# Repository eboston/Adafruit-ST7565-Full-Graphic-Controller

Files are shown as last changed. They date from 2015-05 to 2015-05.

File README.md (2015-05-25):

# Adafruit-ST7565-Full-Graphic-Controller
3D Printer Controller based around the Adafruit ST7565 display

This is a simple project I started to utilize a couple displays I had gotten from 
Adafruit (http://www.adafruit.com/products/250).  Initially this is just for the
RAMPS 1.4 board utilizing the basic smart adapter running Marlin.  Plans are to expand 
the supported platforms to include the Smoothieboard with GLCD shield and the Printrboard 
Rev F4.

Initial support has been added to the devlopment branch of Marlin.

The PCB is Rev B and has not been built or tested yet.  It contains fixes for problems found in the Rev A board.

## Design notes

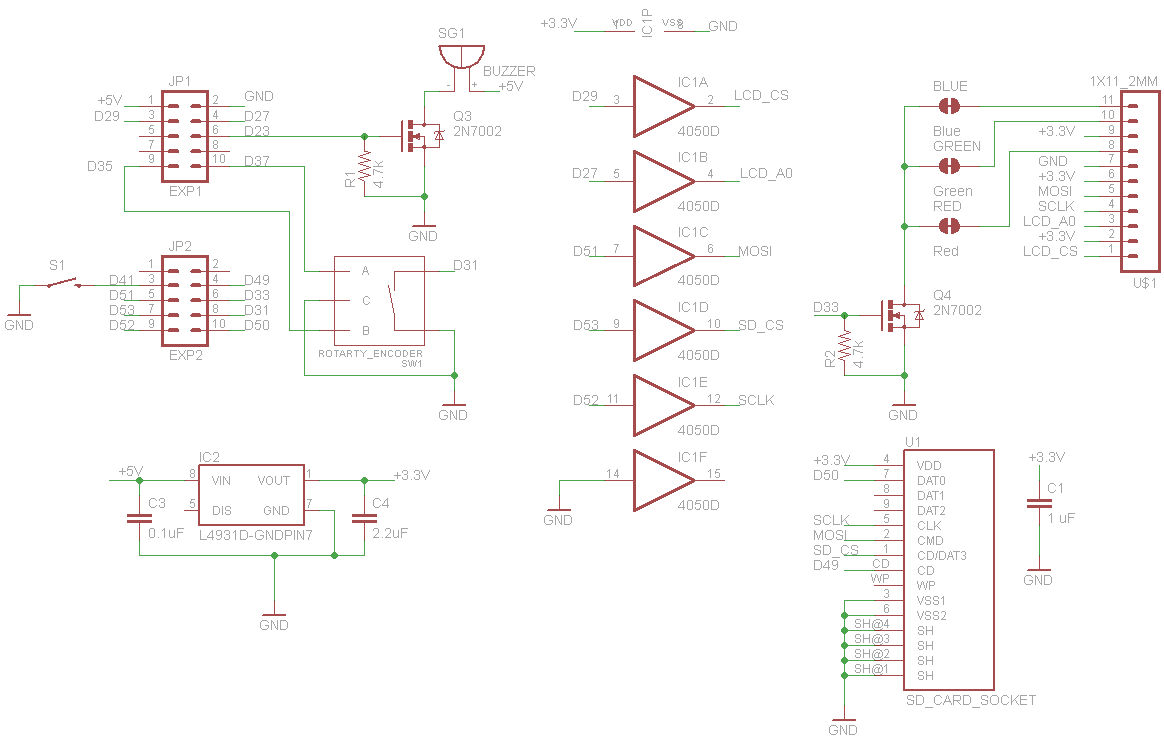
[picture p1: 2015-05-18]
Adafruit ST7565.png

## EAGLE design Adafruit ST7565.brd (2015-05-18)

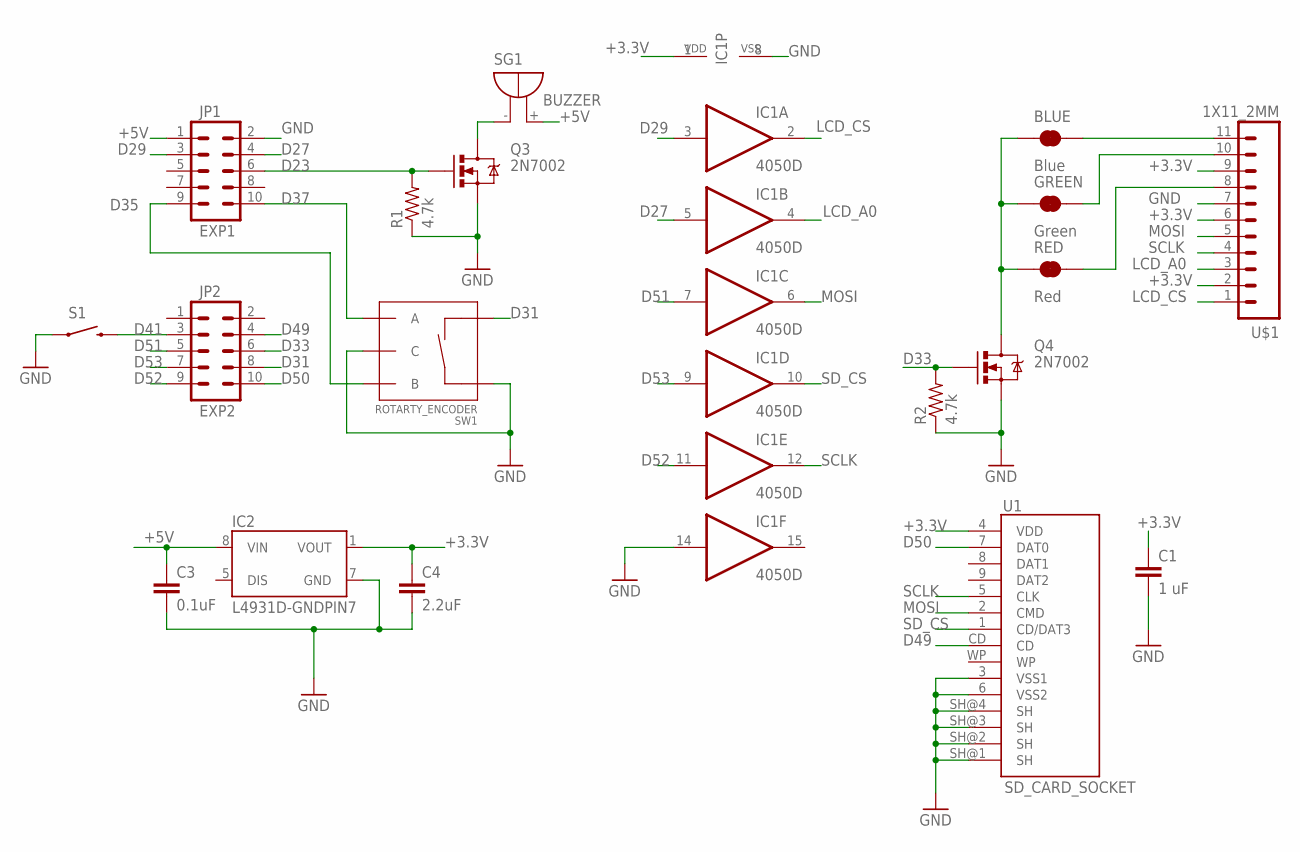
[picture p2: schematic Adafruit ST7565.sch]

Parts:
BLUE: Blue; PAD-JUMPER-2-NC_BY_TRACE_YES_SILK
C1: 1 uF; 1206
C3: 0.1uF; 1206
C4: 2.2uF; 1206
GREEN: Green; PAD-JUMPER-2-NC_BY_TRACE_YES_SILK
IC1: 4050D; SO16
IC2: L4931D-GNDPIN7; SO08
JP1: EXP1; 2X5-SHROUDED
JP2: EXP2; 2X5-SHROUDED
Q3, Q4: 2N7002; SOT23-3
R1, R2: 4.7k; 1206
RED: Red; PAD-JUMPER-2-NC_BY_TRACE_YES_SILK
S1: SWITCH-MOMENTARY-2PTH; TACTILE-PTH
SG1: BUZZER; F/QMBIII
SW1: ROTARTY_ENCODER; ROTARY_ENC_PLAIN
U1: SD_CARD_SOCKET; SD_1:1
U$1: 1X11_2MM

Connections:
+3.3V: C1.1, C4.1, IC1.1 (VDD), IC2.1 (VOUT), U1.4 (VDD), U$1.2, U$1.6, U$1.9
+5V: C3.1, IC2.8 (VIN), JP1.1, SG1.+ (-)
D23: JP1.6, Q3.1 (G), R1.2
D27: IC1.5 (I), JP1.4
D29: IC1.3 (I), JP1.3
D31: JP2.8, SW1.SW-
D33: JP2.6, Q4.1 (G), R2.2
D35: JP1.9, SW1.B
D37: JP1.10, SW1.A
D41: JP2.3, S1.3 (2)
D49: JP2.4, U1.CD
D50: JP2.10, U1.7 (DAT0)
D51: IC1.7 (I), JP2.5
D52: IC1.11 (I), JP2.9
D53: IC1.9 (I), JP2.7
GND: C1.2, C3.2, C4.2, IC1.8 (VSS), IC1.14 (I), IC2.7 (GND), JP1.2, Q3.2 (S), Q4.2 (S), R1.1, R2.1, S1.1, SW1.C, SW1.SW+, U1.3 (VSS1), U1.6 (VSS2), U1.SH@1 (SH), U1.SH@2 (SH), U1.SH@3 (SH), U1.SH@4 (SH), U$1.7
LCD_A0: IC1.4 (O), U$1.3
LCD_CS: IC1.2 (O), U$1.1
MOSI: IC1.6 (O), U1.2 (CMD), U$1.5
unnamed: Q3.3 (D), SG1.- (+)
unnamed: BLUE.1, GREEN.1, Q4.3 (D), RED.1
unnamed: RED.2, U$1.8
unnamed: GREEN.2, U$1.10
unnamed: BLUE.2, U$1.11
SCLK: IC1.12 (O), U1.5 (CLK), U$1.4
SD_CS: IC1.10 (O), U1.1 (CD/DAT3)

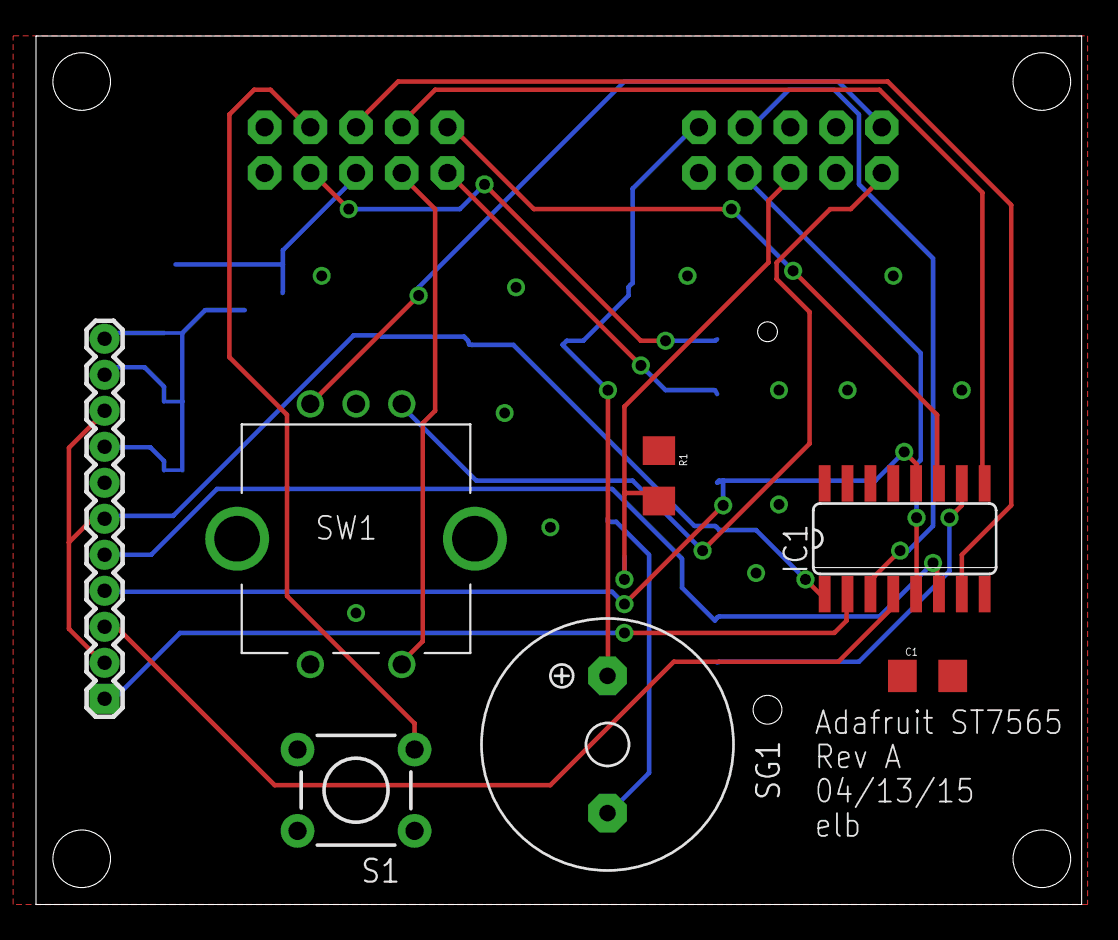
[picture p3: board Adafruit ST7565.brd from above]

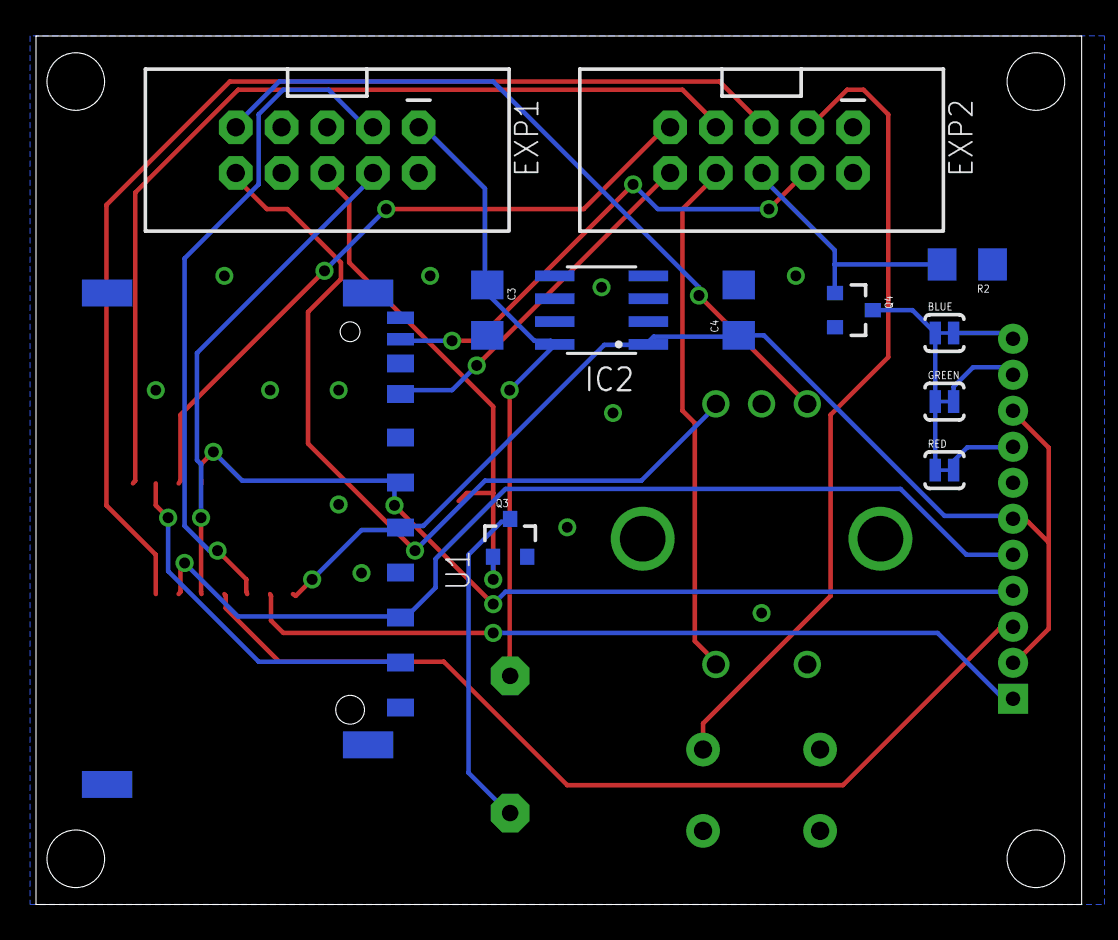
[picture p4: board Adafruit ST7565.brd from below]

Board: 2 copper layers, 58.1 x 48.2 mm, 19 parts (12 on the bottom side), 26 nets.

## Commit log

2015-05-18 Initial Files
    Now it begins
    [Adafruit ST7565.brd, Adafruit ST7565.sch]
2015-05-18 .gitignore
    Ignore Eagle CAD backup and temporary files

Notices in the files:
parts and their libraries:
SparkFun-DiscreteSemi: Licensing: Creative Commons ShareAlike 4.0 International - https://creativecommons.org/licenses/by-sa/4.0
